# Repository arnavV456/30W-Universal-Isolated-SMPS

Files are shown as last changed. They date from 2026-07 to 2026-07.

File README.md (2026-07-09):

# Universal Isolated SMPS

A **30W isolated AC-DC flyback power supply** designed in **KiCad 9**, capable of converting a universal mains input into regulated isolated DC outputs.

This project implements a complete offline SMPS including EMI filtering, surge protection, isolated feedback, custom transformer footprint creation, PCB layout, 3D visualization, and manufacturing outputs.

---

# PCB Top

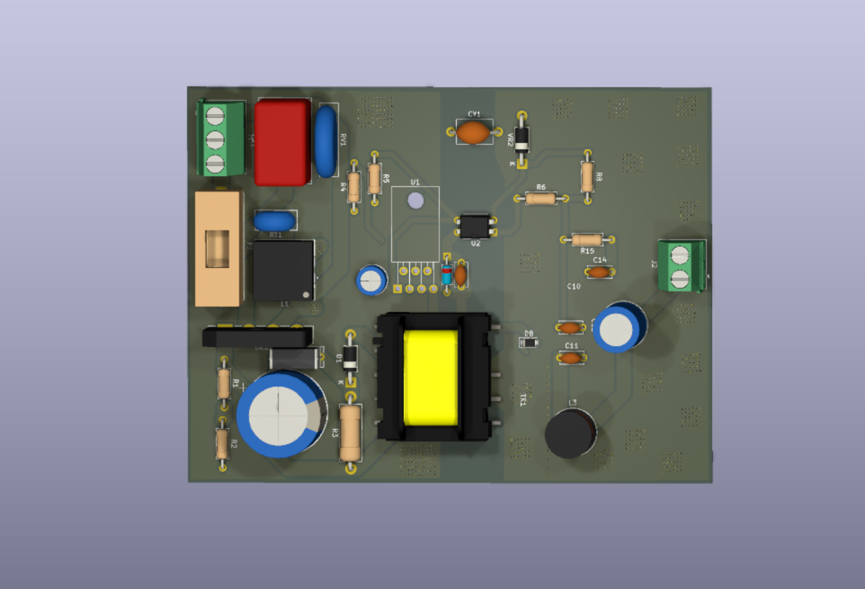
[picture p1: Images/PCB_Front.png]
PCB Top


---

# PCB Bottom

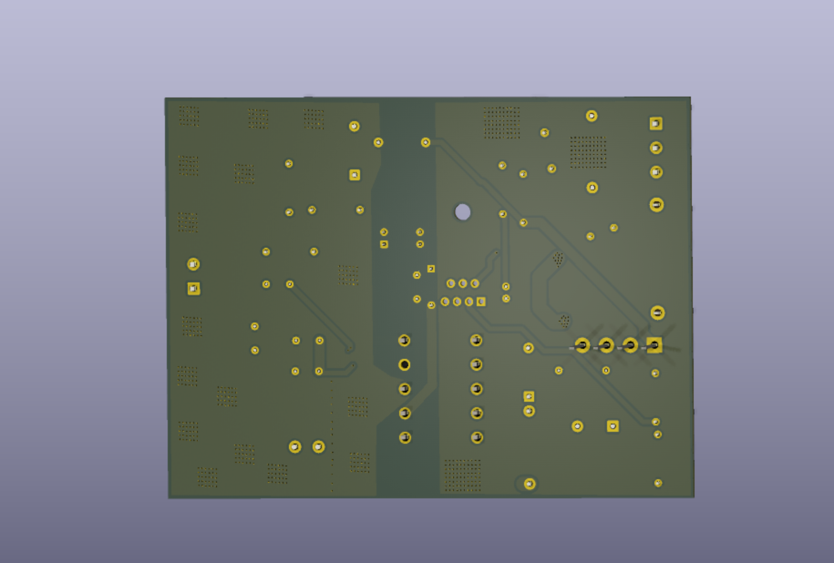
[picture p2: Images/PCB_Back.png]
PCB Bottom


---

## Specifications

| Parameter | Value |
|---|---|
| Input Voltage | 85–265 VAC |
| Output 1 | 12V @ 2.5A |
| Output Power | 30W |
| Isolation | 4 kV |
| Topology | Flyback |
| Controller IC | TOP244Y |
| Transformer | MYRRA 74030 |
| PCB Layers | 2 |

---

# Features

- Universal AC input (85–265 VAC)
- Fully isolated flyback topology
- Reinforced 4 kV isolation
- TOP244Y integrated PWM controller
- Custom MYRRA 74030 transformer footprint & symbol
- EMI input filter
- MOV surge protection
- Fuse protection
- Common-mode choke
- X-Class capacitor
- Y-Class safety capacitor
- Primary RCD snubber network
- Secondary RC snubber
- Schottky output rectification
- Auxiliary transformer winding for controller bias
- Optocoupler-based isolated voltage feedback
- LC output filtering
- High-current PCB routing
- Separate primary and secondary ground planes
- 3D PCB model
- Manufacturing-ready Gerber generation

---

# Functional Overview

### AC Input Stage
- Universal AC input
- Fuse protection
- MOV surge suppressor
- Common-mode choke
- X and Y safety capacitors for EMI suppression

### High Voltage DC Bus
- Full bridge rectifier
- Bulk electrolytic capacitor for DC filtering

### Flyback Converter
- TOP244Y offline switching controller
- MYRRA 74030 flyback transformer
- Auxiliary winding for self-powered operation

### Protection Networks
- Primary RCD snubber to clamp transformer leakage spikes
- Secondary RC snubber to reduce ringing and EMI

### Output Stage
- MBR1060 Schottky rectifier
- LC output filter
- Low ripple 12V output

### Feedback Network
- LTV817A optocoupler
- Zener reference network
- Closed-loop isolated voltage regulation

### Additional Output
- Buck converter generating regulated 5V rail from the 12V output

---

# PCB Design Highlights

- Two-layer PCB
- Custom transformer footprint
- Custom transformer schematic symbol
- Wide power traces for high-current paths
- Dedicated primary HV_RETURN copper pour
- Dedicated secondary return plane
- Isolation barrier between primary and secondary
- Creepage and clearance maintained across isolation boundary
- Optimized placement for reduced switching loop area

---

# Schematic

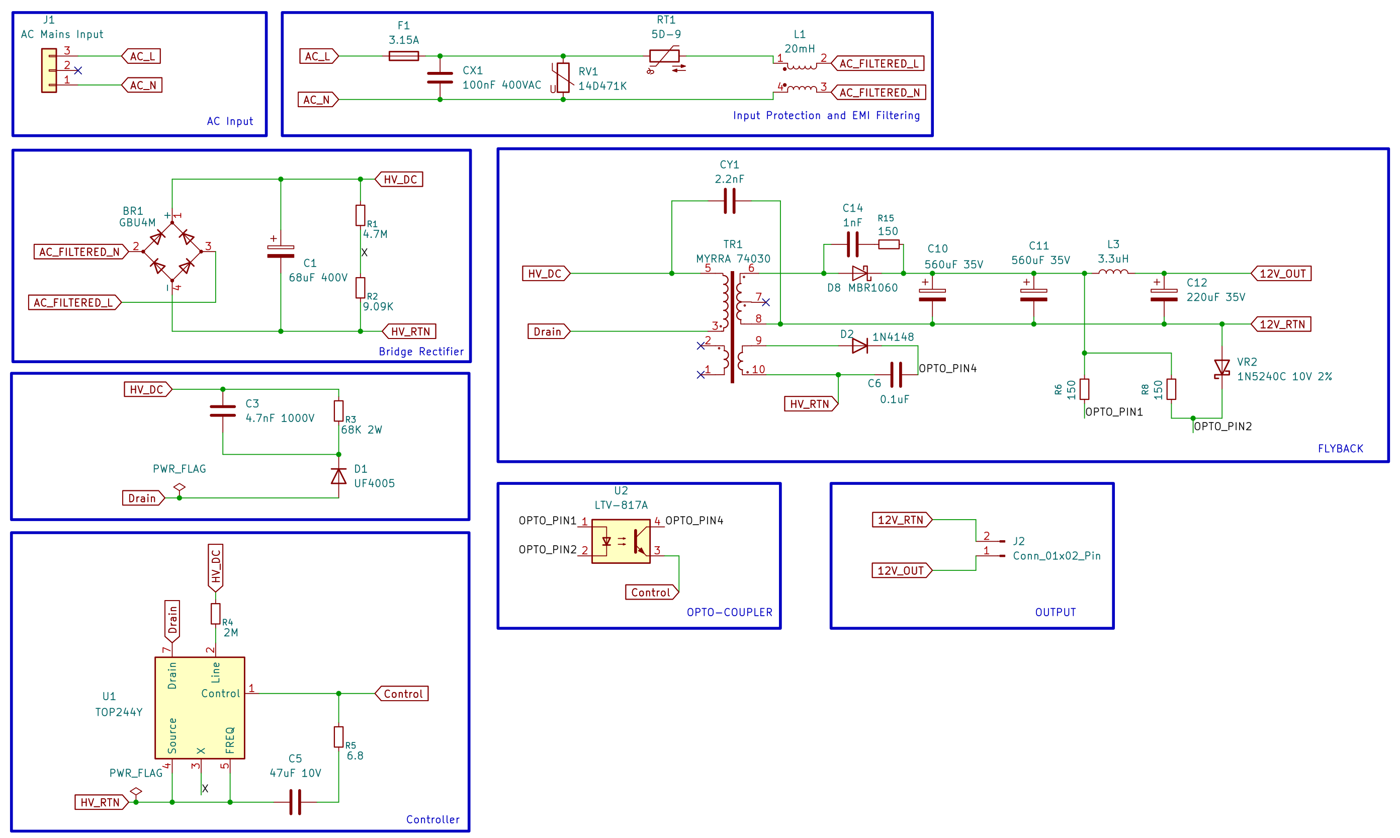
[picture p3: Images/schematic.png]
Schematic


---

# Repository Structure

```
Hardware/
├── universal_30w_smps.kicad_pro
├── universal_30w_smps.kicad_sch
├── universal_30w_smps.kicad_pcb
└── MYRRA.pretty/

Manufacturing/
├── Gerbers
└── Drill Files

Images/
├── PCB_Front.png
├── PCB_Back.png
└── schematic.png

3D Models/

README.md
```

---

# Design Tools

- KiCad 9
- Custom KiCad Libraries
- Git & GitHub

---

# Future Improvements

- Thermal analysis
- Efficiency characterization
- EMI compliance testing
- Hardware validation
- Oscilloscope waveform measurements
- Short-circuit and overload testing

---

## Author

**Arnav Verma**

Electronics & Computer Engineering

Embedded Systems • PCB Design • Power Electronics • IoT • STM32 • ESP32

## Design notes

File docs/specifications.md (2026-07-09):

# Electrical Specification

## Input

| Parameter | Value |
|---|---|
| Input Voltage | 85–265 VAC |
| Input Frequency | 50/60 Hz |
| Input Type | Universal AC |

---

## Outputs

### Output 1 (Primary Output)

| Parameter | Value |
|---|---|
| Voltage | 12 V DC |
| Maximum Current | 2.5 A |
| Maximum Power | 30 W* |

### Output 2 (Auxiliary Output)

---

## Total Output Power

- **30 W Continuous**

---

## Topology

- Isolated Flyback Converter

---

## Controller

- Power Integrations **TOP244Y**

---

## Transformer

- MYRRA **74030**
- 30 W Flyback Transformer
- Reinforced Isolation (4 kV)

---

## Output Regulation

- Primary Output: 12 V

---

## Efficiency Target

- ≥ 85%
- Target: 88% Typical

---

## Protection Features

### Input Protection

- Fuse
- MOV
- NTC Thermistor
- EMI Filter
- X-Class Capacitor
- Y-Class Capacitor

### Converter Protection

- Current Limiting
- Thermal Shutdown
- Soft Start

---

## Isolation

| Parameter | Value |
|---|---|
| Isolation Voltage | 4 kV |
| Creepage Distance | ≥ 6 mm |
| Isolation Type | Reinforced |

---

## Operating Conditions

| Parameter | Value |
|---|---|
| Ambient Temperature | 0–50 °C |
| Cooling | Natural Convection |

---

## PCB

| Parameter | Value |
|---|---|
| Layers | 2 |
| Material | FR4 |
| Thickness | 1.6 mm |
| Copper Weight | 1 oz (35 µm) |
| Isolation Slots | Yes |
| Primary / Secondary Separation | Yes |

---

## Design Goals

- Universal AC Input
- Compact PCB Layout
- High Efficiency
- Reinforced Isolation
- Low EMI
- Reliable Thermal Performance
- Industrial-Grade Design Practices
- Fully Documented Engineering Decisions
- Easy Manufacturing and Assembly

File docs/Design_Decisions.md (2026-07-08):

# Design Decisions

This document outlines the key engineering decisions made during the design of the **Universal 30W Isolated AC-DC Flyback Power Supply**.

---

# Why I Selected the MYRRA 74030 Transformer

The transformer is the heart of an isolated flyback converter, directly influencing efficiency, regulation, thermal performance, and electrical safety.

Instead of using an undocumented generic transformer, I selected the **MYRRA 74030** because it is a commercially manufactured transformer with published specifications, reinforced insulation, and documented electrical characteristics.

The transformer provides:

- 4 kV reinforced isolation
- 6 mm creepage distance
- Universal 85–265 VAC operation
- 30 W continuous power capability
- Published winding specifications
- Proven industrial reliability

Using a transformer with comprehensive manufacturer documentation significantly reduces design risk while improving reliability, repeatability, and long-term maintainability.

---

# Why I Chose the TOP244Y Controller

The **Power Integrations TOP244Y** was selected for its mature offline flyback architecture, integrated high-voltage power MOSFET, and extensive protection features. It is specifically designed for low-to-medium power isolated AC-DC converters operating from universal mains input.

Compared to discrete controller solutions, the TOP244Y significantly reduces component count while maintaining excellent reliability, efficiency, and electromagnetic compatibility.

Advantages include:

- Integrated 700 V power MOSFET
- Universal input (85–265 VAC) operation
- Built-in current limiting
- Thermal shutdown protection
- Soft-start functionality
- Reduced external component count
- Excellent EMI performance
- Proven industrial reliability

These features make it well suited for a compact, isolated 30 W flyback converter.

---

# Why the Flyback Output is 12V / 2.5A

The power supply is designed to deliver a regulated **12 V output capable of supplying up to 2.5 A**, allowing the converter to utilize the full capability of the selected transformer while providing additional flexibility for future applications.

The available output power is shared between:

- External 12 V loads
- On-board 5 V buck converter
- Conversion losses

Designing for the full **30 W** capability provides:

- Additional thermal margin during normal operation
- Greater flexibility for future applications
- Improved support for transient loads
- Better utilization of the transformer
- Lower component stress during typical operation

The 5 V rail is generated from the regulated 12 V output using a high-efficiency buck converter, allowing both outputs to share the available power while maintaining excellent regulation.

---

# Why Generate 5V Using a Buck Converter

Instead of designing a dual-output flyback converter with separate regulated secondary windings, the design regulates a single **12 V output** and derives **5 V** using a high-efficiency buck converter.

Advantages include:

- Better voltage regulation
- Improved cross-load performance
- Simpler transformer design
- Easier compensation
- Lower output ripple
- Reduced design complexity
- Easier debugging and validation
- Greater flexibility for future output voltages

Modern synchronous buck converters typically exceed **90% efficiency**, making this approach highly efficient while maintaining excellent output regulation.

---

# Why Reinforced Creepage and Isolation Were Used

Since this power supply connects directly to the AC mains, electrical isolation between the primary and secondary circuits is essential.

The PCB incorporates:

- Reinforced isolation barrier
- Minimum 6 mm creepage distance
- Isolation slot beneath the transformer
- Isolation slot beneath the optocoupler
- Separate primary and secondary copper pours
- No routing across the isolation barrier

These measures improve electrical safety while reducing the risk of dielectric breakdown during long-term operation.

---

# Why Input Protection Components Were Included

An offline AC-DC converter is exposed to:

- Mains voltage surges
- Inrush current
- Differential-mode noise
- Common-mode noise

The input stage therefore includes:

| Component | Purpose |
|---|---|
| Fuse | Protects against catastrophic faults |
| MOV | Suppresses mains surge voltages |
| NTC Thermistor | Limits inrush current during startup |
| Common-Mode Choke | Reduces conducted common-mode EMI |
| X-Class Capacitor | Suppresses differential-mode noise |
| Y-Class Capacitor | Suppresses common-mode noise while maintaining isolation |

Together, these components improve:

- Electrical safety
- Reliability
- Electromagnetic compatibility (EMC)
- Regulatory compliance

---

# Why Commercially Available Components Were Selected

Wherever possible, commercially available components with comprehensive documentation, established reliability, and long-term availability were selected.

Choosing components from established manufacturers provides several advantages:

- Published electrical characteristics
- Reliable thermal and safety performance
- Consistent manufacturing quality
- Long-term availability
- Easier sourcing and replacement
- Better confidence during design validation

Using well-documented components reduces engineering uncertainty and results in a more robust, maintainable, and reproducible design.

---

# Why the Flyback Topology Was Chosen

Among isolated converter topologies, the flyback converter provides the best balance of simplicity, cost, efficiency, and performance for power levels below approximately **50 W**.

Advantages include:

- Single magnetic component
- Galvanic isolation
- Universal input capability
- Low component count
- Compact PCB footprint
- Mature design ecosystem
- Excellent efficiency in the 20–30 W range
- Wide availability of compatible components

For a universal-input **30 W** AC-DC power supply, the flyback topology provides an ideal balance between performance, manufacturability, reliability, and design complexity.

---

# Project Design Philosophy

The objective of this project is not simply to produce a functioning power supply, but to develop a **professionally engineered offline switch-mode power supply** following industry-standard engineering practices.

The project emphasizes:

- Reliability over minimum cost
- Careful component selection
- High-voltage PCB layout best practices
- Proper creepage and clearance
- Robust thermal performance
- EMI-conscious design
- Comprehensive documentation
- Reproducible engineering decisions

Every major design decision is documented and justified to ensure the final hardware is maintainable, safe, and technically sound.

The completed project is intended to demonstrate practical skills in:

- Offline AC-DC power supply design
- Flyback converter implementation
- High-voltage PCB layout
- Isolation and safety engineering
- Component selection
- Power electronics
- Hardware validation and testing
- Engineering documentation

The goal is to produce a power supply that is not only functional, but also representative of professional engineering practices used in commercial embedded and industrial power electronics.

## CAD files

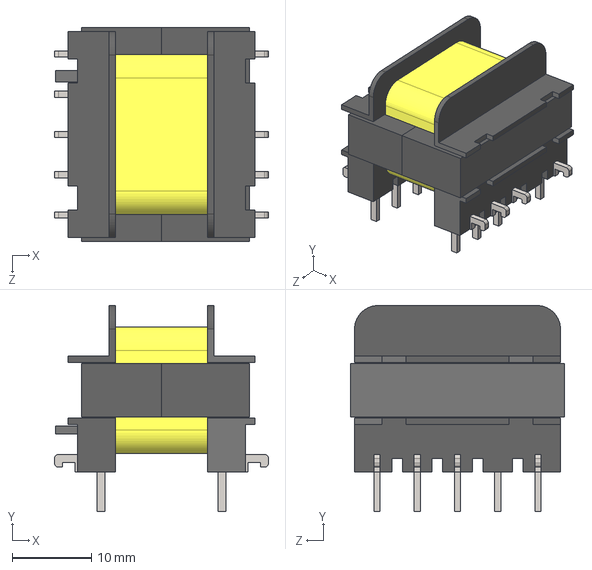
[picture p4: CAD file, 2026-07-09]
3D Models/74030.stp
27.0 x 26.0 x 27.0 mm

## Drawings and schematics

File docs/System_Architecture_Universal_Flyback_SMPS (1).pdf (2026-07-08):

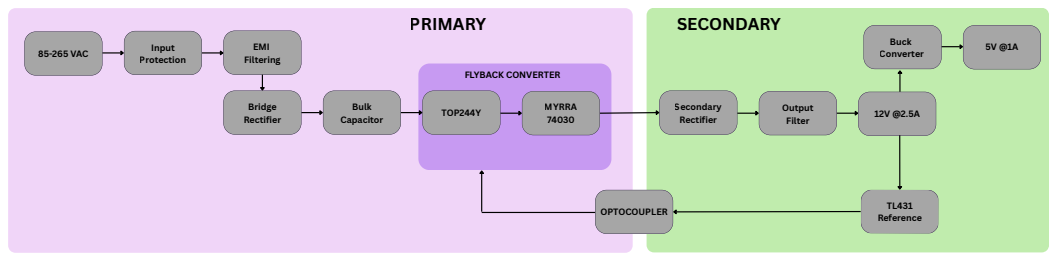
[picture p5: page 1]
85-265 VAC; OPTOCOUPLER; Input Protection; EMI Filtering; Bridge Rectifier; Bulk Capacitor; TOP244Y; MYRRA; FLYBACK CONVERTER; Secondary Rectifier; Output Filter; Buck Converter; TL431 Reference; PRIMARY; SECONDARY

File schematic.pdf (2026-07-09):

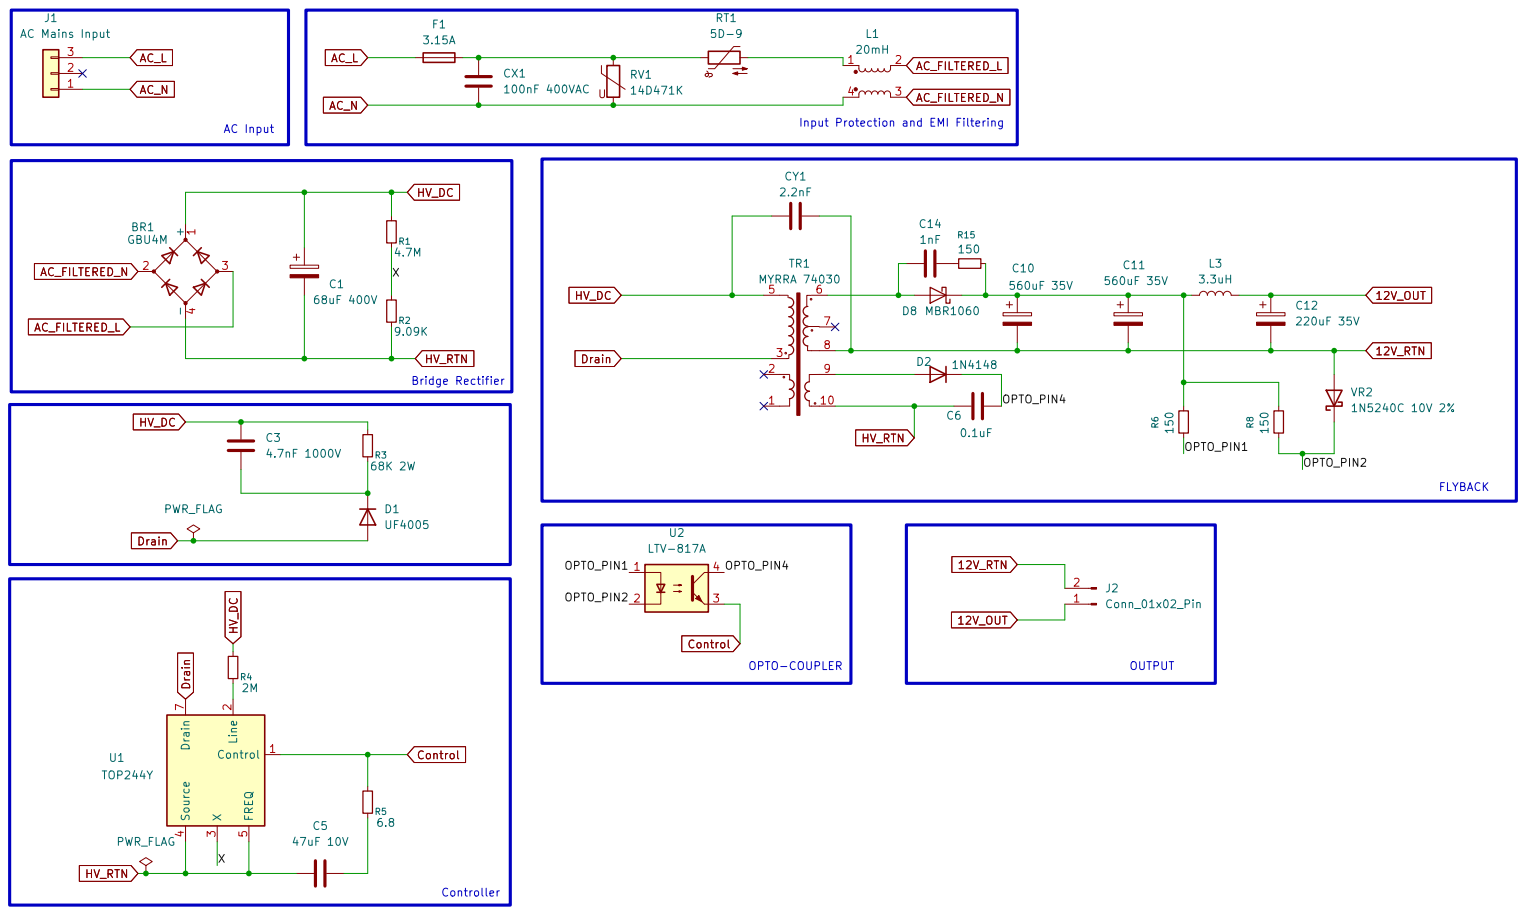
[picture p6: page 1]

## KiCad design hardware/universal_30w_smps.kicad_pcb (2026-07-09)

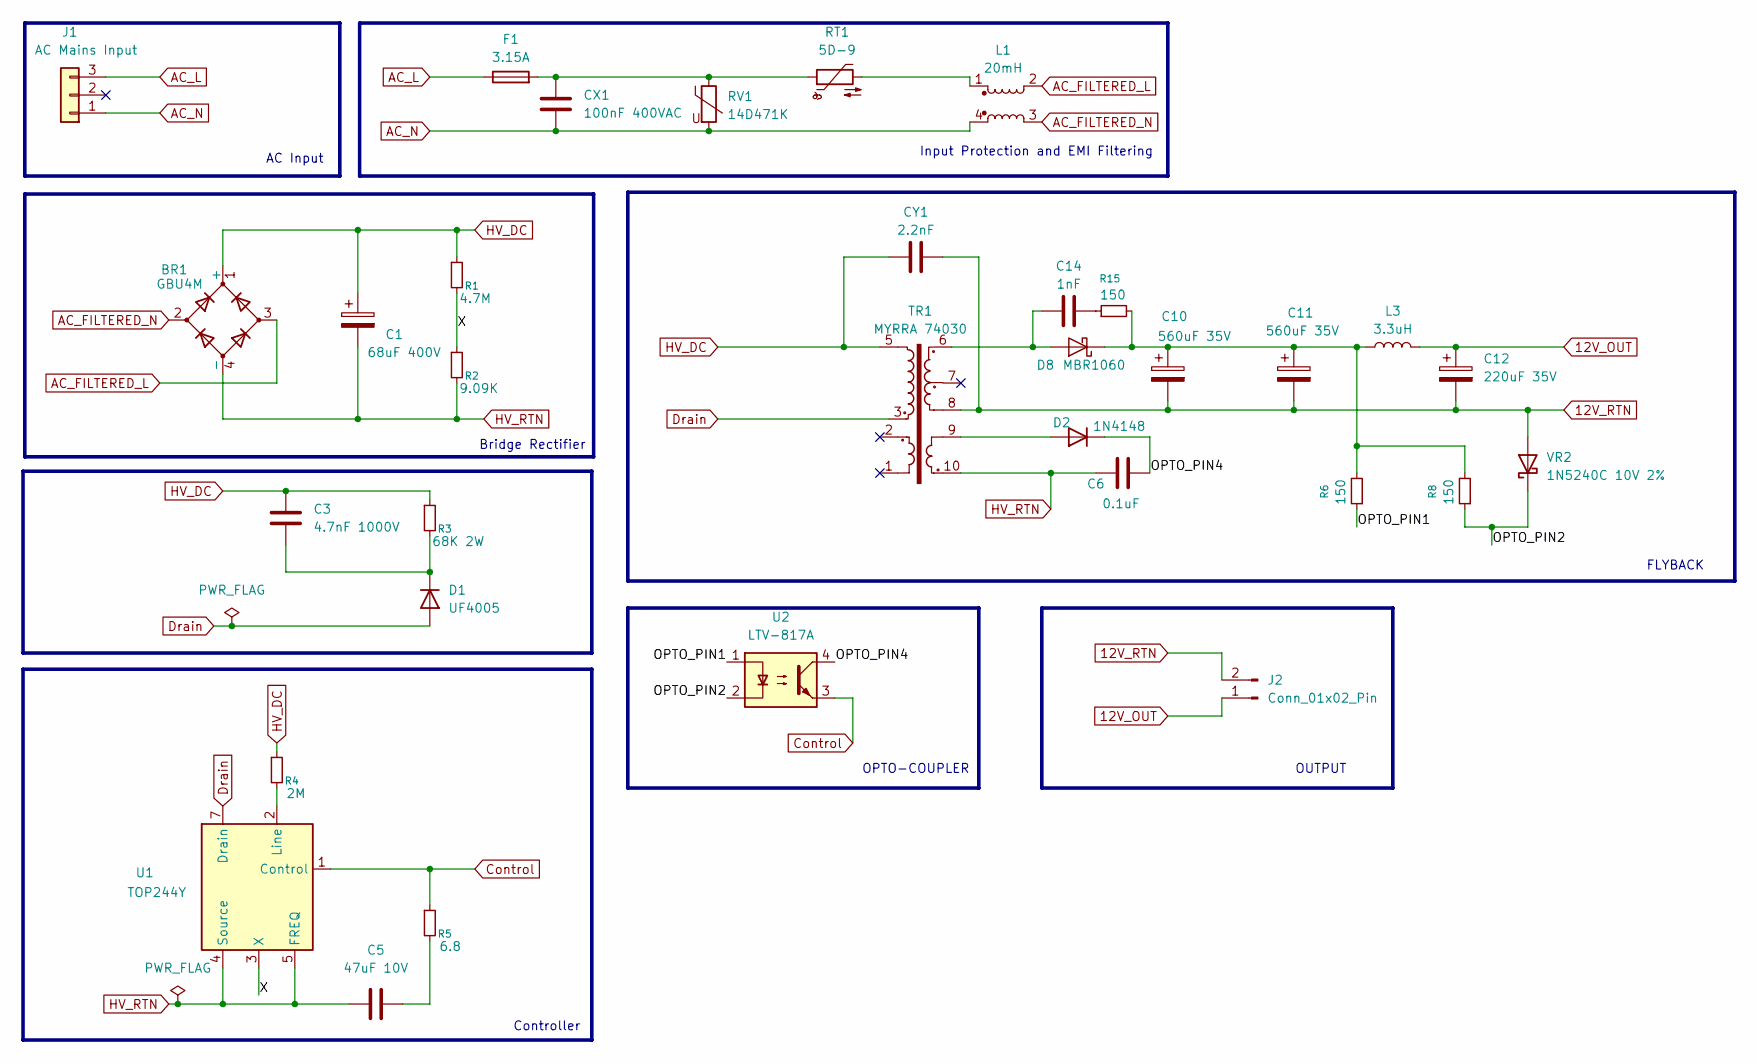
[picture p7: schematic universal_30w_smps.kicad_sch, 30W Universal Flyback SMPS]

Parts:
BR1: GBU4M; Diode_Bridge_Vishay_GBU
C1: 68uF 400V; CP_Radial_D18.0mm_P7.50mm
C3: 4.7nF 1000V; C_Rect_L11.0mm_W4.2mm_P10.00mm_MKT
C5: 47uF 10V; C_Radial_D6.3mm_H5.0mm_P2.50mm
C6: 0.1uF; C_Disc_D5.0mm_W2.5mm_P5.00mm
C10, C11: 560uF 35V; C_Disc_D5.0mm_W2.5mm_P5.00mm
C12: 220uF 35V; C_Radial_D10.0mm_H20.0mm_P5.00mm
C14: 1nF; C_Disc_D5.0mm_W2.5mm_P5.00mm
CX1: 100nF 400VAC; C_Rect_L18.0mm_W11.0mm_P15.00mm_FKS3_FKP3
CY1: 2.2nF; C_Disc_D7.5mm_W5.0mm_P10.00mm
D1: UF4005; D_DO-41_SOD81_P10.16mm_Horizontal
D2: 1N4148; D_DO-35_SOD27_P7.62mm_Horizontal
D8: MBR1060; D_SOD-123F
F1: 3.15A; Fuseholder_Cylinder-5x20mm_Stelvio-Kontek_PTF78_Horizontal_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
J1: AC Mains Input; TerminalBlock_Phoenix_MKDS-1,5-3-5.08_1x03_P5.08mm_Horizont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
J2: Conn_01x02_Pin; TerminalBlock_Phoenix_MKDS-1,5-2-5.08_1x02_P5.08mm_Horizont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
L1: 20mH; L_CommonModeChoke_Bourns_SRF1260
L3: 3.3uH; L_Radial_D10.0mm_P5.00mm_Fastron_07P
R1: 4.7M; R_Axial_DIN0207_L6.3mm_D2.5mm_P10.16mm_Horizontal
R2: 9.09K; R_Axial_DIN0207_L6.3mm_D2.5mm_P10.16mm_Horizontal
R3: 68K 2W; R_Axial_DIN0414_L11.9mm_D4.5mm_P15.24mm_Horizontal
R4: 2M; R_Axial_DIN0207_L6.3mm_D2.5mm_P10.16mm_Horizontal
R5: 6.8; R_Axial_DIN0207_L6.3mm_D2.5mm_P10.16mm_Horizontal
R6, R8, R15: 150; R_Axial_DIN0207_L6.3mm_D2.5mm_P10.16mm_Horizontal
RT1: 5D-9; RV_Disc_D9mm_W4.2mm_P5mm
RV1: 14D471K; RV_Disc_D15.5mm_W4mm_P7.5mm
TR1: MYRRA 74030; Transformer_Myrra_74030_Horizontal
U1: TOP244Y; TO-220-7_P2.54x3.8mm_StaggerOdd_Lead5.85mm_TabDown
U2: LTV-817A; DIP-4_W7.62mm
VR2: 1N5240C 10V 2%; D_DO-41_SOD81_P10.16mm_Horizontal

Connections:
12V_OUT: C12.1, J2.1, L3.2
12V_RTN: C10.2, C11.2, C12.2, CY1.2, J2.2, TR1.8, VR2.2 (A)
/OPTO_PIN1: R6.1, U2.1
/OPTO_PIN2: R8.1, U2.2, VR2.1 (K)
/OPTO_PIN4: C6.2, D2.1 (K), U2.4
/X: R1.2, R2.1, U1.3 (X)
AC_FILTERED_L: BR1.3, L1.2
AC_FILTERED_N: BR1.2, L1.3
AC_L: F1.1, J1.3
AC_N: CX1.2, J1.1, L1.4, RV1.2
Control: R5.1, U1.1 (Control), U2.3
Drain: D1.2 (A), TR1.3, U1.7 (Drain)
HV_DC: BR1.1 (+), C1.1, C3.1, CY1.1, R1.1, R3.1, R4.1, TR1.5
HV_RTN: BR1.4 (-), C1.2, C5.1, C6.1, R2.2, TR1.10, U1.4 (Source), U1.5 (FREQ)
unnamed: C5.2, R5.2
unnamed: C14.2, R15.1
unnamed: CX1.1, F1.2, RT1.1, RV1.1
unnamed: C3.2, D1.1 (K), R3.2
unnamed: D2.2 (A), TR1.9
unnamed: C14.1, D8.2 (A), TR1.6
unnamed: C10.1, C11.1, D8.1 (K), L3.1, R6.2, R8.2, R15.2
unnamed: L1.1, RT1.2
unnamed: R4.2, U1.2 (Line)

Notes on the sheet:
OUTPUT
FLYBACK
OPTO-COUPLER
Input Protection and EMI Filtering
Bridge Rectifier
AC Input
Controller

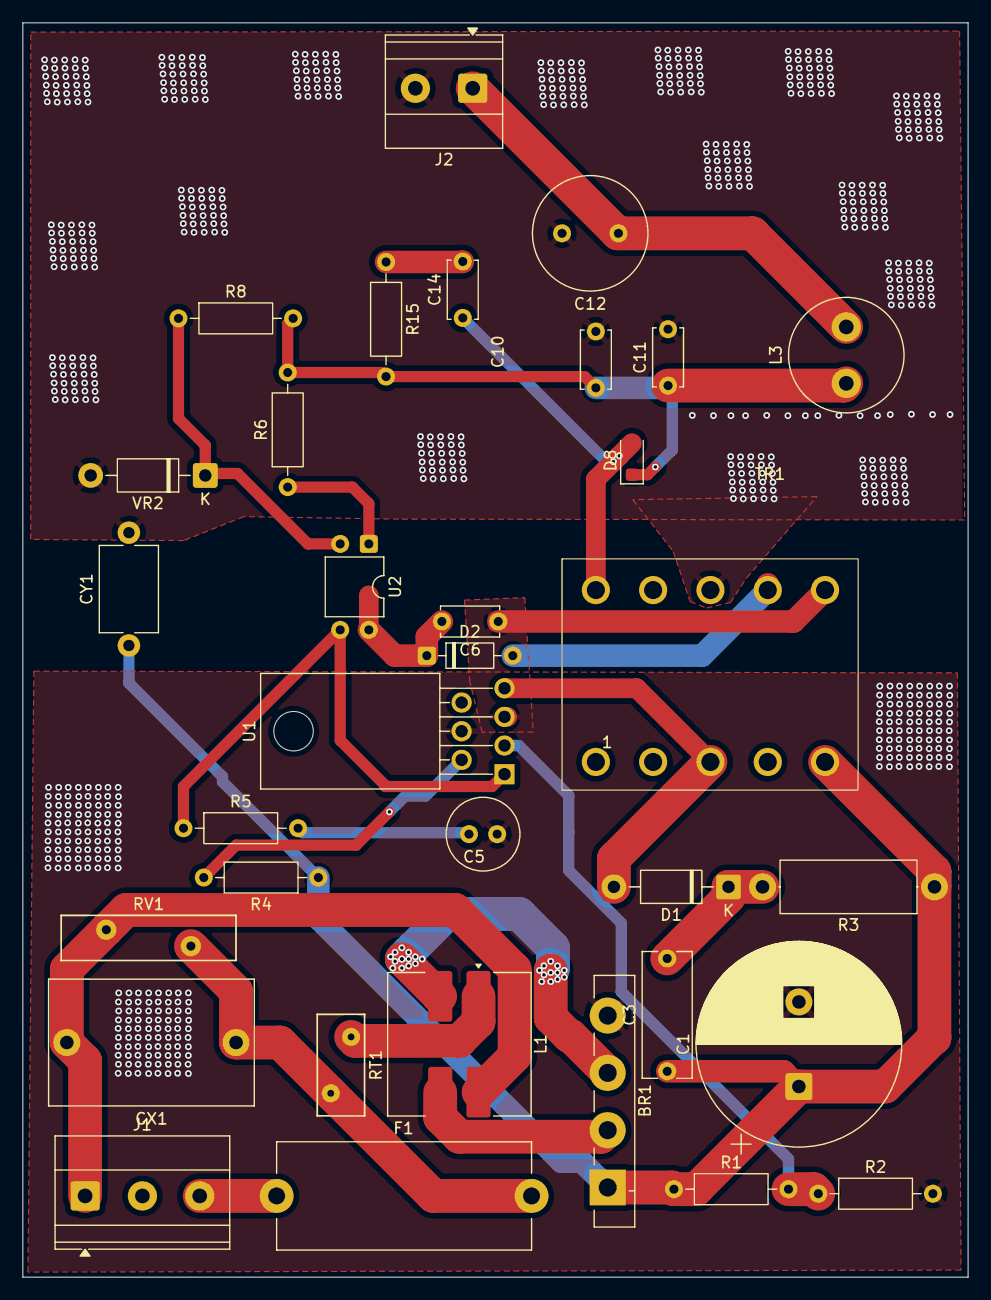
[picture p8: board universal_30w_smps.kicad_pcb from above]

Board: 2 copper layers, 83.8 x 111.2 mm, 33 parts (0 on the bottom side), 23 nets.

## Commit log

2026-07-08 Document design decisions for power supply components
    Expanded design decisions for the power supply, detailing component selections, topology choices, and safety measures. Included rationale for using commercially available components and design consid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
2026-07-08 Revise Design Decisions for 24W AC-DC Flyback Supply
    This document outlines the engineering decisions made during the design of the Universal 24W Isolated AC-DC Flyback Power Supply, detailing component selections and design philosophies.
2026-07-08 Revise electrical specifications to tabular format
    Updated the electrical specifications to a tabular format for better readability and added detailed parameters for inputs, outputs, and PCB characteristics.
2026-07-09 add manufacturing files
    [universal_30w_smps-B_Cu.gbr, universal_30w_smps-B_Mask.gbr, universal_30w_smps-B_Paste.gbr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]
2026-07-09 schematic pdf
2026-07-09 pcb images
2026-07-09 Add PCB images to README
    Added images of PCB top and bottom to README.
2026-07-09 schematic image
2026-07-09 Add schematic section to README
    Add schematic section with image reference
2026-07-09 Remove auxiliary output specifications
    Removed details about the auxiliary output parameters and note regarding power budget.
